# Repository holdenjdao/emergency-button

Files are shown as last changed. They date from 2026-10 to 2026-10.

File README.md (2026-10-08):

# Emergency Button

ESP32-C3 board with an L86 GNSS module, a single emergency push button, and coin cell or USB-C power. Designed in EasyEDA Pro, revision V1.0 (2025-12-01).

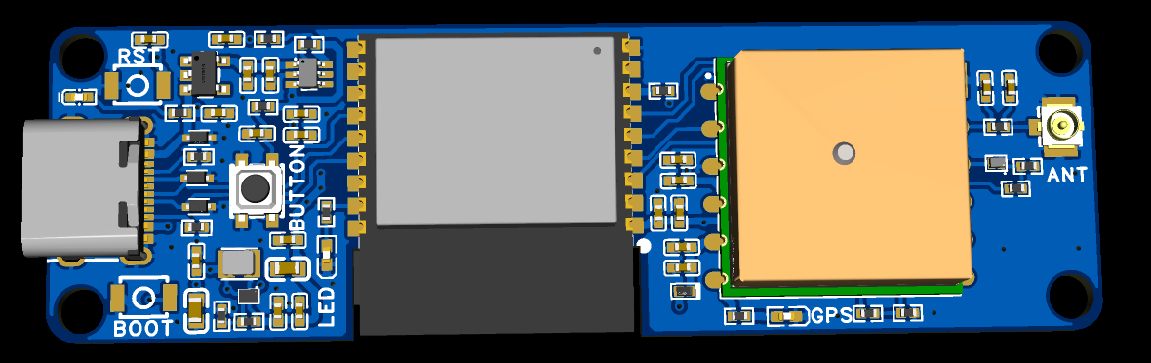
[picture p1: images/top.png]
Top view


## Specifications

| Item | Part |
| --- | --- |
| MCU | ESP32-C3-WROOM-02-N4 (U1) |
| GNSS | Quectel L86-M33 (U7), patch antenna plus U.FL connector (U8) |
| Battery boost | TI TPS61099 (U5), 3.3 V output |
| USB regulator | TI TLV75733P (U9), 5 V to 3.3 V |
| Power path | TI LM66100 ideal diode (U10) |
| Battery | Coin cell, BS-8-1 holder (B1) |
| Connector | USB-C, power and programming |
| Inputs | Emergency button (SW3), BOOT (SW1), RESET (SW2) |
| Indicators | Power LED (LED2), user LED (LED3), GNSS 1PPS LED (LED1) |

## Design Notes

- Programming uses the ESP32-C3 native USB Serial/JTAG on GPIO18/GPIO19. No USB-to-UART bridge is required.
- USB-C sink configuration uses 5.1 kΩ pull-downs on CC1 and CC2 (R3, R4). D+, D-, and VBUS have ESD protection (U2 to U4).
- The GNSS backup supply (V_BCKP) is fed from 3.3 V through a Schottky diode (D1) with a 4.7 µF hold-up capacitor (C18). This retains backup data across brief supply interruptions and supports hot start.
- GNSS reset is driven through an NPN transistor (Q1) in open-collector configuration. The MCU never drives the module reset pin directly.
- The emergency button is debounced in hardware with a 10 kΩ pull-up and 100 nF capacitor (R7, C16).
- The U.FL antenna path includes a pi-match footprint (R10, C21, C22) for tuning.

## MCU Pin Assignment

| GPIO | Function |
| --- | --- |
| IO1 | User LED |
| IO3 | Emergency button |
| IO4 | GNSS RXD |
| IO5 | GNSS TXD |
| IO6 | GNSS reset |
| IO7 | GNSS FORCE_ON |
| IO8 | Strapping, 10 kΩ pull-up |
| IO9 | BOOT button |
| IO18 / IO19 | USB D- / D+ |
| EN | RESET button, RC delay (R1, C3) |

## Schematic

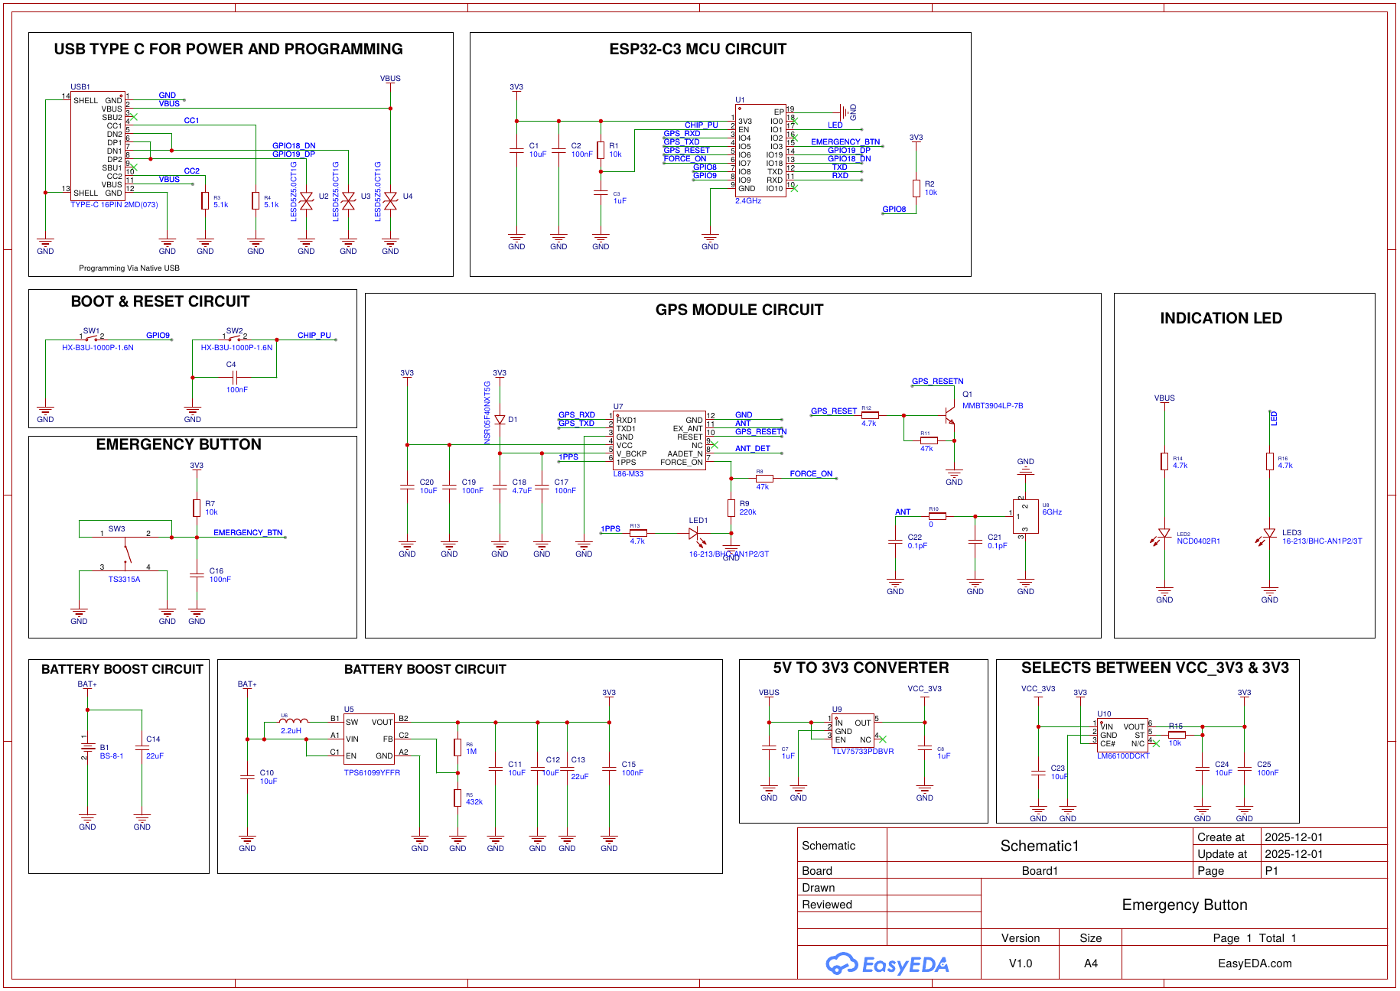
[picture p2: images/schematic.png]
Schematic


PDF: [schematic/schematic.pdf](schematic/schematic.pdf)

## Board

| Top | Bottom |
| --- | --- |
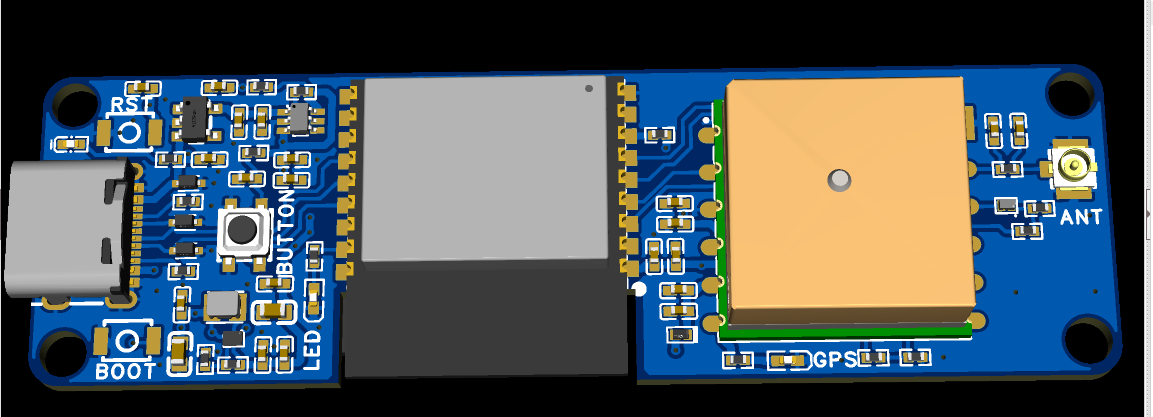
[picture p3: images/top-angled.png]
Top angled
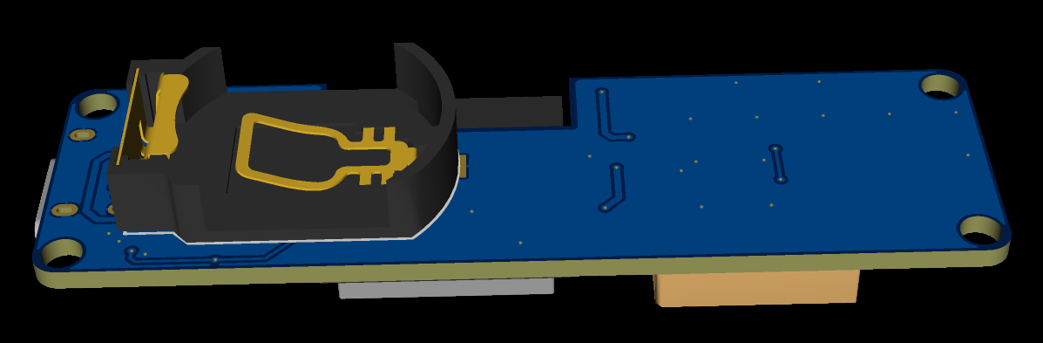
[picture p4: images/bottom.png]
Bottom
|  |  |

## Repository Contents

| Path | Contents |
| --- | --- |
| `schematic/` | Schematic (PDF) |
| `source/` | EasyEDA Pro project file (.epro) |
| `fabrication/` | Gerber files, bill of materials, pick-and-place |
| `3d/` | STEP model |
| `images/` | Renders and schematic image |

## Manufacturing

The BOM uses LCSC part numbers. Upload `fabrication/gerber.zip`, `fabrication/bom.csv`, and `fabrication/pick-and-place.csv` to JLCPCB for fabrication and assembly.

## Author

Holden Dao

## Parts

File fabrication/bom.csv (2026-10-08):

No. | Quantity | Comment | Designator | Footprint | Value | Manufacturer Part | Manufacturer | Supplier Part | Supplier | LCSC Part Name
1 | 1 | BS-8-1 | B1 | BAT-TH_BS-8-1 |  | BS-8-1 | QIJEY | C70378 | LCSC | 镀金 BS-8-1
2 | 7 | 10uF | C1,C10,C11,C12,C20,C23,C24 | C0402 | 10uF | CL05A106MP5NUNC | SAMSUNG(三星) | C315248 | LCSC | 10uF ±20% 10V
3 | 7 | 100nF | C2,C4,C15,C16,C17,C19,C25 | C0402 | 100nF | CL05B104KB54PNC | SAMSUNG(三星) | C307331 | LCSC | 100nF ±10% 50V
4 | 3 | 1uF | C3,C7,C8 | C0402 | 1uF | CL05A105KO5NNNC | SAMSUNG(三星) | C29266 | LCSC | 1uF ±10% 16V
5 | 2 | 22uF | C13,C14 | C0603 | 22uF | CL10A226MO7JZNC | SAMSUNG(三星) | C2762594 | LCSC | 22uF ±20% 16V
6 | 1 | 4.7uF | C18 | C0402 | 4.7uF | CL05A475MP5NRNC | SAMSUNG(三星) | C23733 | LCSC | 4.7uF ±20% 10V
7 | 2 | 0.1pF | C21,C22 | C0402 | 0.1pF | GJM1555C1HR10WB01D | muRata(村田) | C161338 | LCSC | ±0.05pF 0.1pF 50V
8 | 1 | NSR05F40NXT5G | D1 | DSN2_L1.0-W0.6-RD |  | NSR05F40NXT5G | onsemi(安森美) | C146713 | LCSC | 电压:40V 电流:500mA
9 | 2 | 16-213/BHC-AN1P2/3T | LED1,LED3 | LED0402-R-RD |  | 16-213/BHC-AN1P2/3T | EVERLIGHT(亿光) | C131223 | LCSC | 蓝灯
10 | 1 | NCD0402R1 | LED2 | LED0402-RD |  | NCD0402R1 | 国星光电 | C130719 | LCSC | 片式发光二极管
11 | 1 | MMBT3904LP-7B | Q1 | X1-DFN1006-3_L1.0-W0.6-BR |  | MMBT3904LP-7B | DIODES(美台) | C154763 | LCSC | NPN 电流:200mA 电压:40V
12 | 4 | 10kΩ | R1,R2,R7,R15 | R0402 | 10kΩ | 0402WGF1002TCE | UNI-ROYAL(厚声) | C25744 | LCSC | 10kΩ ±1% 62.5mW 厚膜电阻
13 | 2 | 5.1kΩ | R3,R4 | R0402 | 5.1kΩ | 0402WGF5101TCE | UNI-ROYAL(厚声) | C25905 | LCSC | 5.1kΩ ±1% 62.5mW 厚膜电阻
14 | 1 | 432kΩ | R5 | R0402 | 432kΩ | 0402WGF4323TCE | UNI-ROYAL(厚声) | C25787 | LCSC | 432kΩ ±1% 62.5mW 厚膜电阻
15 | 1 | 1MΩ | R6 | R0402 | 1MΩ | 0402WGF1004TCE | UNI-ROYAL(厚声) | C26083 | LCSC | 1MΩ ±1% 62.5mW 厚膜电阻
16 | 2 | 47kΩ | R8,R11 | R0402 | 47kΩ | 0402WGJ0473TCE | UNI-ROYAL(厚声) | C25563 | LCSC | 47kΩ ±5% 62.5mW 厚膜电阻
17 | 1 | 220kΩ | R9 | R0402 | 220kΩ | 0402WGF2203TCE | UNI-ROYAL(厚声) | C25767 | LCSC | 220kΩ ±1% 62.5mW 厚膜电阻
18 | 1 | 0Ω | R10 | R0402 | 0Ω | 0402WGF0000TCE | UNI-ROYAL(厚声) | C17168 | LCSC | 0Ω ±1% 62.5mW 厚膜电阻
19 | 4 | 4.7kΩ | R12,R13,R14,R16 | R0402 | 4.7kΩ | 0402WGF4701TCE | UNI-ROYAL(厚声) | C25900 | LCSC | 4.7kΩ ±1% 62.5mW 厚膜电阻
20 | 2 | HX-B3U-1000P-1.6N | SW1,SW2 | SW-SMD_2P-L3.0-W2.5-LS4.0 |  | HX-B3U-1000P-1.6N | hanxia(韩下) | C49234121 | LCSC | 3*2.5*1.6mm 立贴 轻触开关
21 | 1 | TS3315A | SW3 | SW-SMD_4P-L3.4-W3.4-P2.00-LS4.0 |  | TS3315A | SHOU HAN(首韩) | C412367 | LCSC | 3.3*3.3*1.5mm 立贴 轻触开关
22 | 1 | 2.4GHz | U1 | BULETM-SMD_ESPRESSIF_ESP32-C3-WROOM-02-N4-4MB | 2.4GHz | ESP32-C3-WROOM-02-N4 | ESPRESSIF(乐鑫) | C2934560 | LCSC | ESP32-C3-WROOM-02-N4
23 | 3 | LESD5Z5.0CT1G | U2,U3,U4 | SOD-523_L1.2-W0.8-LS1.6-BI |  | LESD5Z5.0CT1G | HXY MOSFET(华轩阳电子) | C5451650 | LCSC | 5V 15PF 双向
24 | 1 | TPS61099YFFR | U5 | DSBGA-6_L0.8-W1.2-P0.40-R3-C2-TL |  | TPS61099YFFR | TI(德州仪器) | C91091 | LCSC | TPS61099x超低静态电流同步升压转换器
25 | 1 | 2.2uH | U6 | IND-SMD_L2.0-W1.6 | 2.2uH | VLS201610CX-2R2M-1 | TDK | C2041554 | LCSC | 2.2uH ±20% 1.31A
26 | 1 | L86-M33 | U7 | GPSM-SMD_12P-L16.0-W16.0-P2.54-BL |  | L86-M33 | Quectel(移远) | C909689 | LCSC | 超紧凑的GNSS POT模块
27 | 1 | 6GHz | U8 | IPEX-SMD_BWIPX-1-001E | 6GHz | BWU.FL-IPEX1 | BAT WIRELESS(蝙蝠无线) | C5137195 | LCSC | 内针 IPEX
28 | 1 | TLV75733PDBVR | U9 | SOT-23-5_L2.9-W1.6-P0.95-LS2.8-BL |  | TLV75733PDBVR | TI(德州仪器) | C485517 | LCSC | 具有使能功能的 1A、低 IQ、高精度、低压降稳压器
29 | 1 | LM66100DCKT | U10 | SC-70-6_L2.0-W1.3-P0.65-LS2.1-BL |  | LM66100DCKT | TI(德州仪器) | C2832141 | LCSC | LM66100DCKT
30 | 1 | TYPE-C 16PIN 2MD(073) | USB1 | USB-C-SMD_TYPE-C-6PIN-2MD-073 |  | TYPE-C 16PIN 2MD(073) | SHOU HAN(首韩) | C2765186 | LCSC | Type-C 母 卧贴

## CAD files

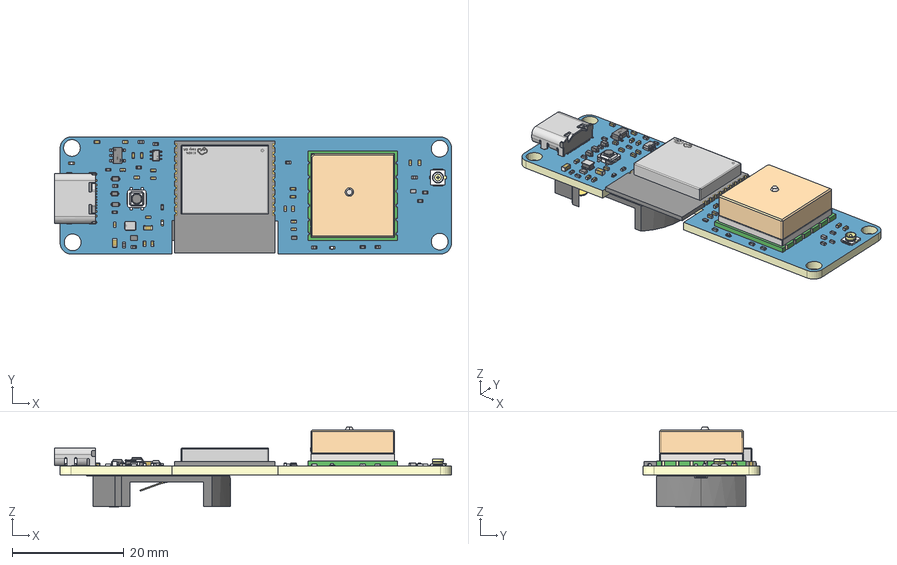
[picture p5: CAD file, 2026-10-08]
3d/emergency-button.step
71.0 x 21.0 x 14.3 mm
Board~GGZ1
TopCopper~GGZ1
BottomCopper~GGZ1
TopFpcStiffener~GGZ1
BottomFpcStiffener~GGZ1
C0402~C0402_L1.0-W0.5-H0.5~GGZ1 x 20
R0402~R0402_L1.0-W0.5-H0.4~GGZ1 x 16
C0603~C0603_L1.6-W0.8-H0.8~GGZ1 x 2
LED0402-RD~LED0402_L1.0-W0.5-H0.2~GGZ1
DSN2_L1.0-W0.6-RD~DSN2_L1.0-W0.6-RD~GGZ1
LED0402-R-RD~LED0402_L1.0-W0.5-H0.4~GGZ1 x 2
SOD-523_L1.2-W0.8-LS1.6-BI~SOD-523_L1.2-W0.8-LS1.6-BI~GGZ1 x 3
X1-DFN1006-3_L1.0-W0.6-BR~X1-DFN1006-3_L1.0-W0.6-H0.5-BR~GGZ1
DSBGA-6_L0.8-W1.2-P0.40-R3-C2-TL~DSBGA-6_ L0.8-W1.2-H0.6-P0.40-R3-C2-TL~GGZ1
IPEX-SMD_BWIPX-1-001E~IPEX-SMD_BWIPX-1-001E~GGZ1
SW-SMD_4P-L3.4-W3.4-P2.00-LS4.0~SW-SMD_4P-L3.4-W3.4-P2.00-LS4.0~GGZ1 x 2
BULETM-SMD_ESPRESSIF_ESP32-C3-WROOM-02-N4-4MB~BULETM-SMD_ESPRESSIF_ ESP32-C3-WROOM-02-N4-4MB~GGZ1
GPSM-SMD_12P-L16.0-W16.0-P2.54-BL~GPSM-SMD_ 12P-L16.0-W16.0-P2.54-BL~GGZ1
IND-SMD_L2.0-W1.6~IND-SMD_L2.0-W1.6-H1.1~GGZ1
SC-70-6_L2.0-W1.3-P0.65-LS2.1-BL~SC-70-6_L2.0-W1.3-P0.65-LS2.1-BL~GGZ1
SOT-23-5_L2.9-W1.6-P0.95-LS2.8-BL~SOT-23-5_ L2.9-W1.6-P0.95-LS2.8-BL~GGZ1
USB-C-SMD_TYPE-C-6PIN-2MD-073~USB-C-SMD_TYPE-C-6PIN-2MD-073~GGZ1
BAT-TH_BS-8-1~BAT-TH_BS-8-1~GGZ1

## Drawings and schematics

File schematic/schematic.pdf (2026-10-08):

# USB TYPE C FOR POWER AND PROGRAMMING

# ESP32-C3 MCU CIRCUIT

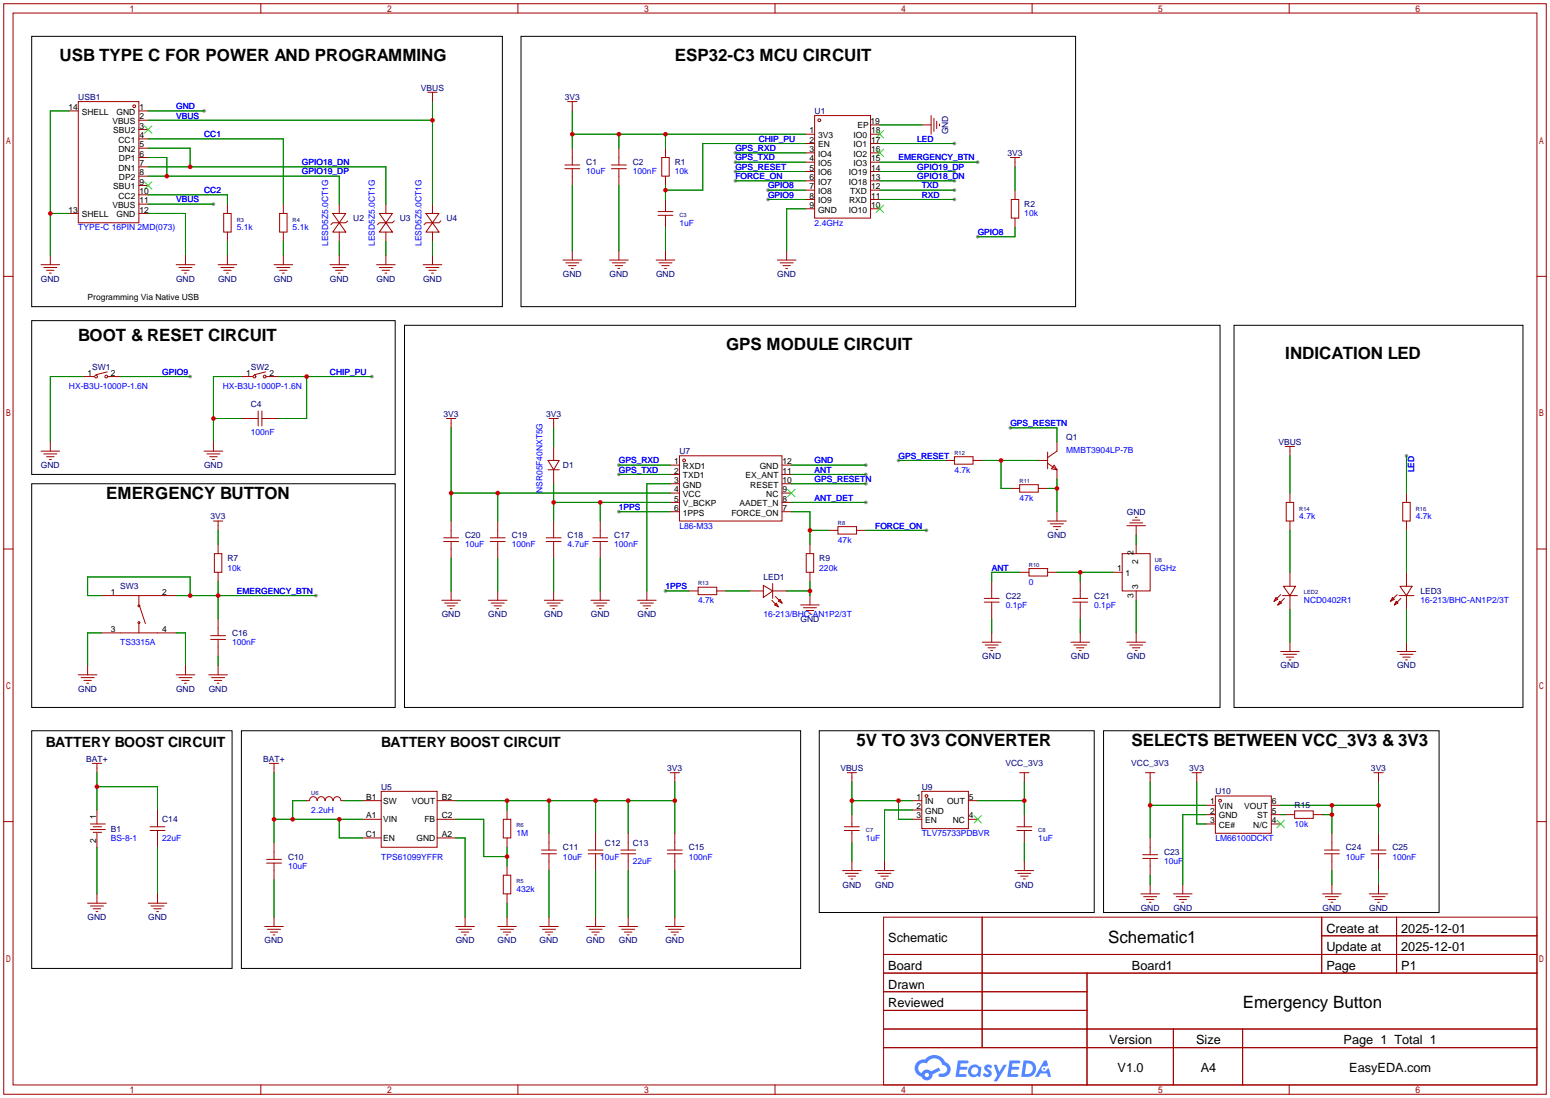
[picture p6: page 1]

Programming Via Native USB
BOOT & RESET CIRCUIT

Schematic | Schematic1 | Create at | 2025-12-01

Update at | 2025-12-01

Board | Board1 | Page | P1
Drawn | | Emergency Button
Reviewed

Version | Size | Page 1 Total 1
V1.0 | A4 | EasyEDA.com
